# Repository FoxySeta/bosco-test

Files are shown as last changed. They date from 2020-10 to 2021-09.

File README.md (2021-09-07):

# Bosco Test

Bosco tests are designed to assess the morphofunctional characteristics of one's
legs muscles as well as their neuromuscular skills.

## Acknowledgements

Many thanks to Camilla M. Asioli, for her diligent work, and Alice Viglino, for
her enthusiastic efforts.

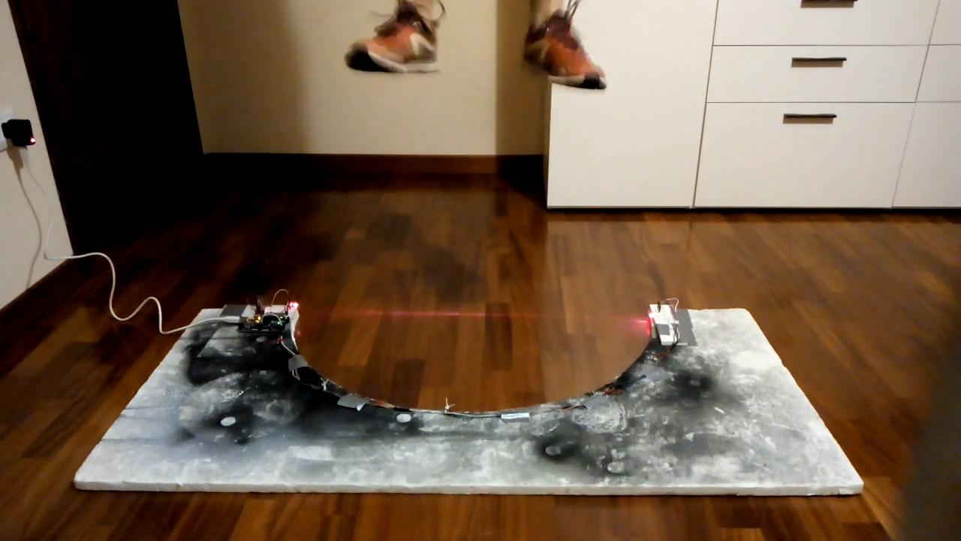
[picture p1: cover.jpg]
Cover


## Components and supplies

- [Arduino Mega 2560](https://store.arduino.cc/arduino-mega-2560-rev3) × 1.
  Actually, pretty much any Arduino board would do just fine.
- [Breadboard (generic)](https://www.newark.com/multicomp/mcbb400/breadboard-solderless-abs/dp/99W1759?COM=ref_hackster)
  × 2
- [Jumper wires(generic)](https://www.newark.com/adafruit/759/wire-gauge-28awg/dp/88W2571?COM=ref_hackster)
  × 30.
  Please consider the quantity indicated above a generic rule of thumb.
- [ICStation KY-008 Laser Transmitter Module](https://www.amazon.com/s?k=ICStation+KY-008+Laser+Transmitter+Module)
  × 1
- [Photo resistor](https://www.adafruit.com/product/161) × 1
- [Resistor 10k ohm](https://www.newark.com/multicomp/mccfr0w4j0103a50/carbon-film-resistor-10kohm-250mw/dp/58K5002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)
  × 1
- [HC-05 Bluetooth Module](https://www.amazon.com/HiLetgo-Wireless-Bluetooth-Transceiver-Arduino/dp/B071YJG8DR)
  × 1
- Android device × 1

## Apps and online services

- [Arduino IDE](https://www.arduino.cc/en/main/software)
- [MIT App Inventor 2](http://appinventor.mit.edu/)

## About this project

### Why the Bosco test?

Even though several similar products are already available on the market, their
price range is often ridiculously high for a sports club trying to run a simple
physical fitness test. As high school students practicing sports after school,
we decided to do something about it. After a little bit of researching on the
net, we realized that most of the sensors and data usually featured by such
systems aren't even taken into consideration by your everyday athlete. Our new
goal: to start cutting down on every unneeded asset.

### How does it work?

A laser barrier detects whether the athlete's feet are currently touching the
ground or not. For every jump, the delay between two "touching-the-ground"
instants is memorized as the ToF (time of flight) for that particular jump.
Finally, this information is sent via Bluetooth to a connected Android device,
which deducts the JH (jump height) using a simple formula (g being the
[gravitational acceleration](https://en.wikipedia.org/wiki/Gravitational_acceleration):

> JH = (ToF ^ 2 * g) / 8

### Assembling your circuit

See [here](https://create.arduino.cc/projecthub/camice-foxyseta/bosco-test-a90dd3#toc-assembling-your-circuit-2).

### Uploading the sketch

Follow these simple steps to upload your sketch:

1. create a folder named "test_di_bosco" in your sketchbook folder
2. download the six source files embed below inside your new "test_di_bosco" folder
3. open `test_di_bosco.ino` using Arduino IDE: a single window with all of the
   `.ino` files in it should open
4. that's it: you are now ready to upload the entire sketch clicking on "upload"
   once

### A sample Android application

We chose to use MIT App Inventor 2 (see Apps and online services) to develop our
[sample application](http://ai2.appinventor.mit.edu/?galleryId=5968109044891648)
(available for free).

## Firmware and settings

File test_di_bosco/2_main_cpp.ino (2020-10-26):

// 2_main_cpp: il punto di ingresso del programma (contiene setup() e void())

namespace {
	constexpr int pin_laser_inizio { 2 },
				  pin_laser_fine { 3 },
				  pin_fotoresistenza_inizio { 0 },
				  pin_fotoresistenza_fine { 1 },
				  pin_bluetooth_trasmettitore { 10 },
				  pin_bluetooth_ricevitore { 11 };
	
	Apparecchiatura::Barriera pedana(pin_laser_inizio, pin_laser_fine, pin_fotoresistenza_inizio, pin_fotoresistenza_fine);
	Connessione::Terminale operatore(pedana, pin_bluetooth_trasmettitore, pin_bluetooth_ricevitore); 
}

void setup() {
	operatore.setup();
}

void loop() {
	operatore.loop();
}

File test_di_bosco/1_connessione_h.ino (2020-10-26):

// 1_connessione_h: intestazione del modulo di connessione bluetooth al terminale

#ifndef CONNESSIONE_H
#define CONNESSIONE_H

#include <SoftwareSerial.h>

namespace Connessione {

	class Terminale {
	public:
		// inizializzazione obbligatoria
		Terminale(Apparecchiatura::Barriera& barriera, int pin_tra, int pin_ric,
				  long baud = baud_def, HardwareSerial& debug = Serial, long baud_debug = baud_debug_def);
		Terminale(Apparecchiatura::Barriera& barriera, int pin_tra, int pin_ric,
				  HardwareSerial& debug, long baud_debug = baud_debug_def);
		Terminale() = delete;
		// spostamento consentito
		Terminale(Terminale&&) = default;
		Terminale& operator=(Terminale&&) = default;
		// copia vietata: un pin dovrebbe appartenere a un solo terminale
		Terminale(const Terminale&) = default;
		Terminale& operator=(const Terminale&) = delete;
		// distruttore predefinito
		~Terminale() = default;

		// costanti
		static constexpr long baud_def { 9600 }, baud_debug_def { 9600 };
		static constexpr char comando_stato { '0' }, // chiede se la barriera sia accesa
							  comando_spegni { '1' }, // spegne la barriera
							  comando_accendi { '2' }, // accende la barriera
							  comando_chiedi { '3' }, // chiede una prova di N salti
							  comando_abortisci { '4' }; // annulla la richiesta
		static constexpr int salti_richiesti_default { 1 };
		static constexpr size_t salti_richiesti_string_dim { 10 };

		// getter
		Apparecchiatura::Barriera& barriera() const;
		int pin_tra() const;
		int pin_ric() const;
		long baud() const;
		HardwareSerial& debug() const;
		long baud_debug() const;

		void setup();
		void loop();

	private:
		Apparecchiatura::Barriera& bar; // la barriera controllata dal terminale
		int pin_tx, pin_rx; // pin del flusso di comunicazione col terminale
		SoftwareSerial m; // modulo per la comunicazione col terminale
		long b; // velocità di trasmissione (in baud) col terminale
		HardwareSerial& d; // pin del flusso di comunicazione per debug
		long b_d; // velocità di trasmissione (in baud) per debug 

		void azione_stato();
		void azione_spegni();
		void azione_accendi();
		void azione_chiedi();
		bool azione_aborto();
		void azione_sconosciuta(char input);

		int calcola_salti_richiesti();
	};
	
}

#endif

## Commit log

2021-07-11 Add FZZ
    [bosco_test_wOr8uHrcy7.fzz]
2021-07-11 Rename FZZ
    [bosco_test.fzz]
